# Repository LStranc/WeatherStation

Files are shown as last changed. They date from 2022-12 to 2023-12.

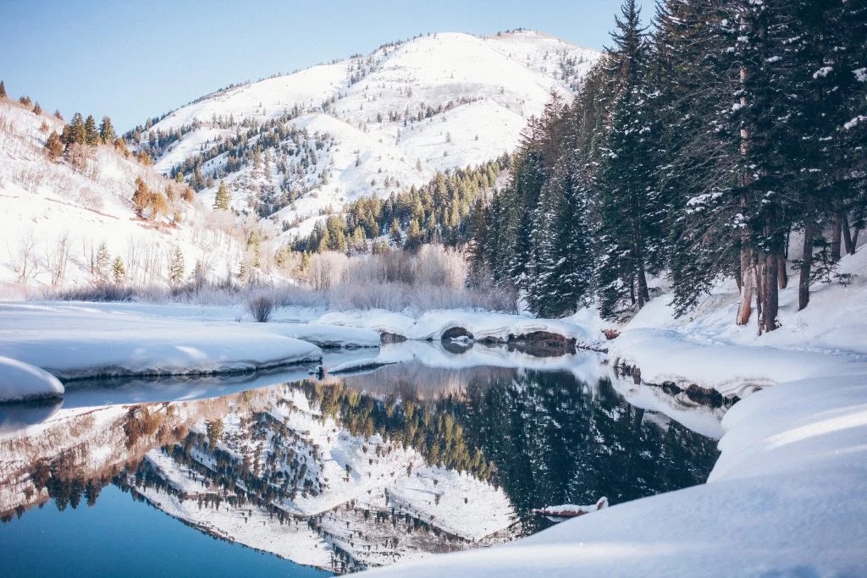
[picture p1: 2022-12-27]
Server_Code/weatherstation/pictures/UtahMountainLake.jpg

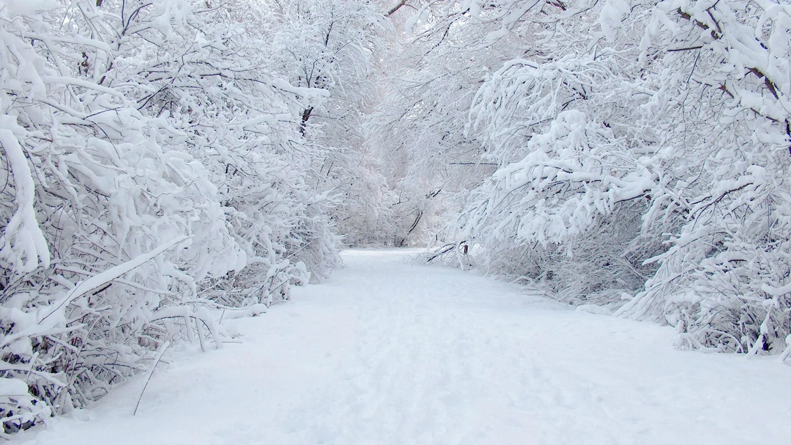
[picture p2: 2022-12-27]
Server_Code/weatherstation/pictures/pictures/snowfall.jpg

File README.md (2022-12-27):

# WeatherStation
The goal of this project was to build a cordless personal weather station that can be put in your own backyard. The weather station sends data to a server and you can analyze, store and use the data in anyway you want. 

This project includes c file to upload to the microcontroller, the server files used to store data in the sql database and display it to the website, and the schematic and pcb files for the actual hardware.

## Hardware
The Mircocontoller I used in this project is the esp32. A more generalized arudino code file is uploaded to this repo also. The weather station reads temperature, humidity, and pressure through a BME280 chip. It has a water sensor to sense if it is rainig. It uses the solar panel to tell how bright/sunny it is outside. This solar panel is also charging the lipo battery that it is powering the weather station. There is a uv sensor that tells us the uv index. There is Wind Sensor Rev P made by Modern Devices that is able to measure the windspeed. Also, there is a PWM5005 sensor which measures the air quality. The esp samples each sensor input then sends the data wirelessly to the server.

## Server
The server stores the data from the weather station and puts it in a mySQL database. The server also hosts a website where a client can interact with current and previously stored data. 

## Future 
This project is still in progress but the hope for the future is to implement an machine algorithm to try to forcast the upcoming weather.

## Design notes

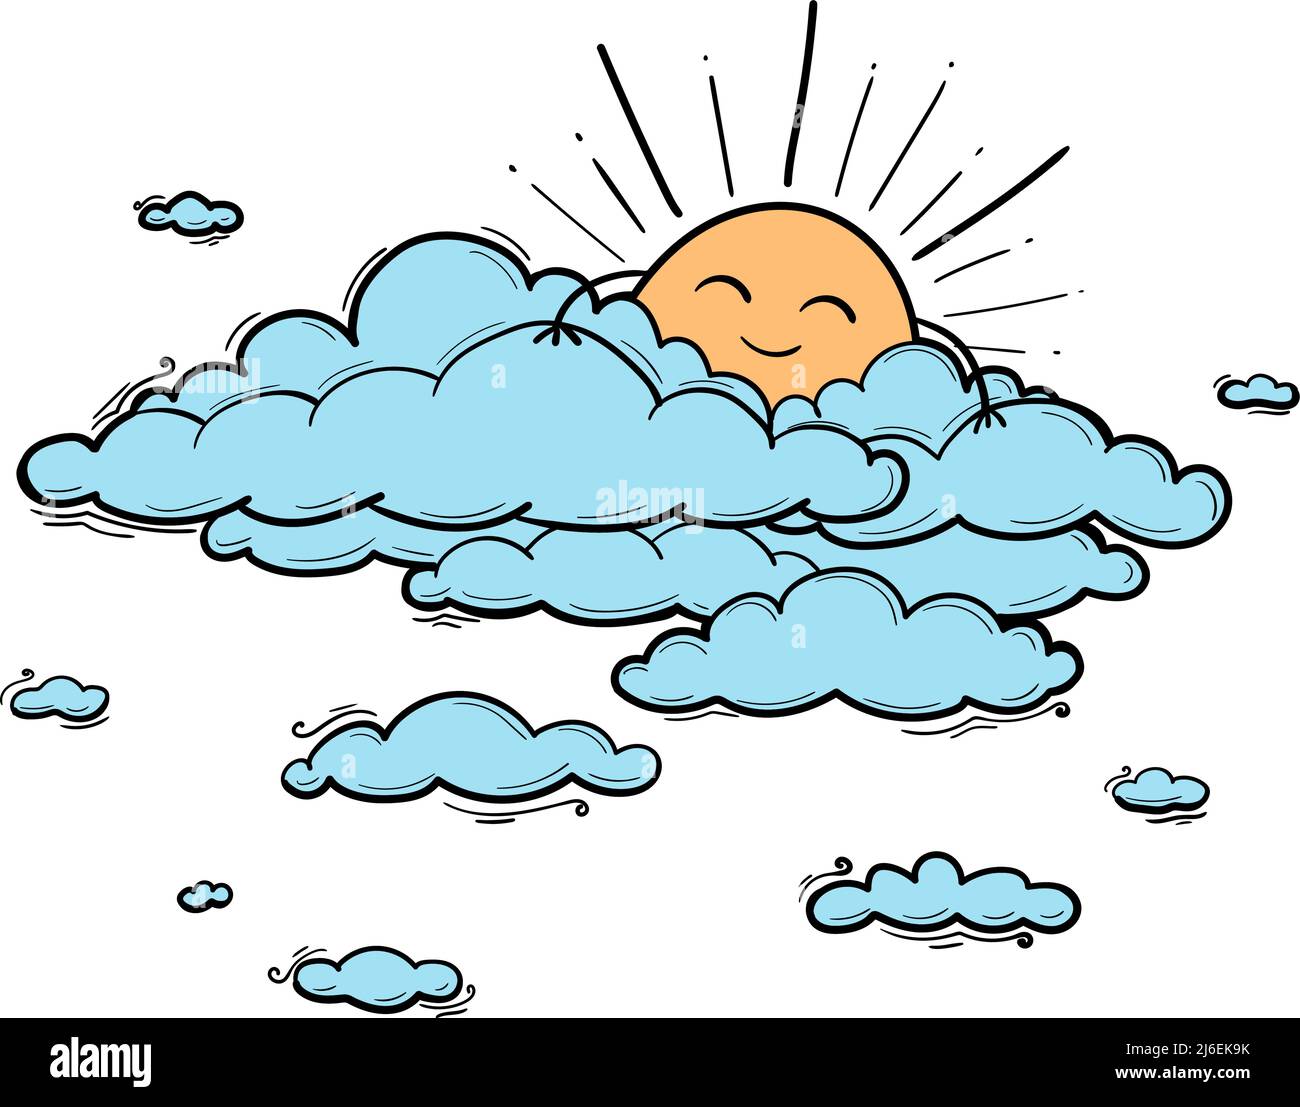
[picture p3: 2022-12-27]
Server_Code/weatherstation/pictures/CloudyDrawing.jpg

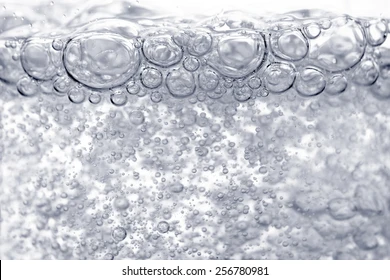
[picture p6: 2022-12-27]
Server_Code/weatherstation/pictures/boilingwater.webp

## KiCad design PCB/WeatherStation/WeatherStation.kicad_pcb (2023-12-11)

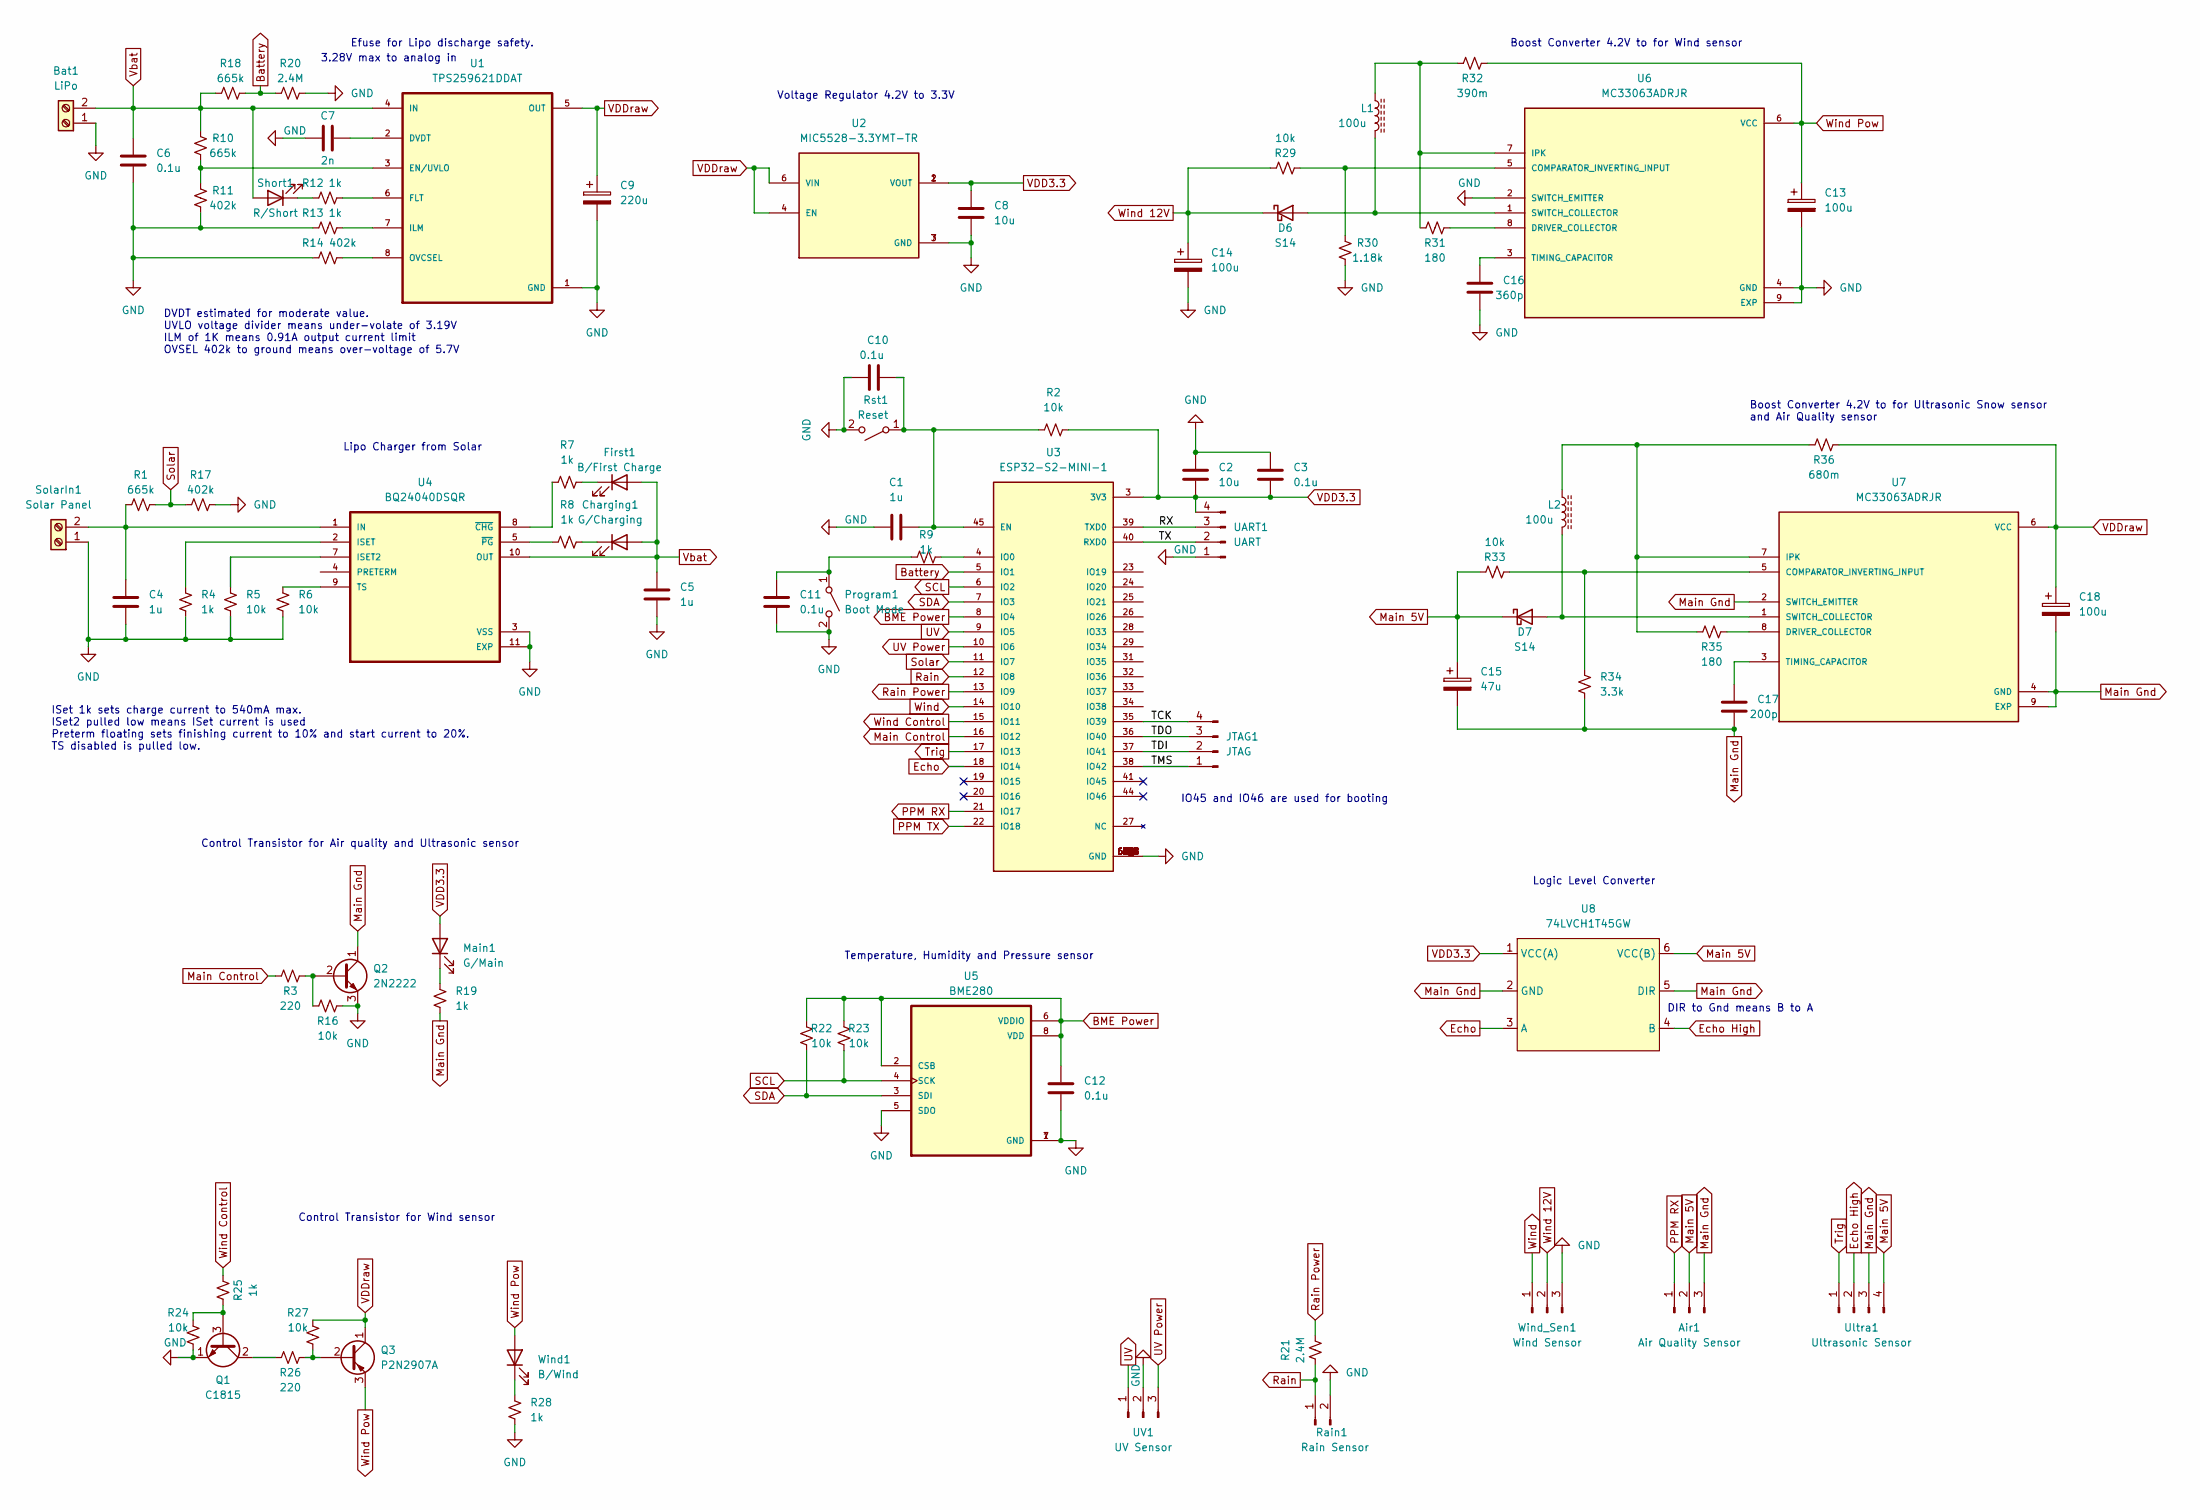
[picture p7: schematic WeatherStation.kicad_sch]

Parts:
Air1: Air Quality Sensor; PinHeader_1x03_P2.54mm_Vertical
Bat1: LiPo; TerminalBlock_Altech_AK300-2_P5.00mm
C1, C4, C5: 1u; C_0603_1608Metric_Pad1.08x0.95mm_HandSolder
C2, C8: 10u; C_0805_2012Metric_Pad1.18x1.45mm_HandSolder
C3, C6, C10, C11, C12: 0.1u; C_0603_1608Metric_Pad1.08x0.95mm_HandSolder
C7: 2n; C_0603_1608Metric_Pad1.08x0.95mm_HandSolder
C9: 220u; C_Radial_D5.0mm_H11.0mm_P2.00mm
C13, C18: 100u; C_Radial_D5.0mm_H11.0mm_P2.00mm
C14: 100u; C_Radial_D6.3mm_H11.0mm_P2.50mm
C15: 47u; C_Radial_D4.0mm_H7.0mm_P1.50mm
C16: 360p; C_0402_1005Metric_Pad0.74x0.62mm_HandSolder
C17: 200p; C_0603_1608Metric_Pad1.08x0.95mm_HandSolder
Charging1: G/Charging; LED_0603_1608Metric_Pad1.05x0.95mm_HandSolder
D6, D7: S14; D_SOD-123F
First1: B/First Charge; LED_0603_1608Metric_Pad1.05x0.95mm_HandSolder
JTAG1: JTAG; PinHeader_1x04_P2.54mm_Vertical
L1, L2: 100u; L_Toroid_Vertical_L10.2mm_W3.8mm_P3.8mm
Main1: G/Main; LED_0603_1608Metric_Pad1.05x0.95mm_HandSolder
Program1: Boot Mode; SW_PUSH_6mm_H5mm
Q1: C1815; TO-92
Q2: 2N2222; TO-92
Q3: P2N2907A; TO-92
R1, R10, R18: 665k; R_0603_1608Metric_Pad0.98x0.95mm_HandSolder
R2, R5, R6, R16, R22, R23, R24, R27, R29, R33: 10k; R_0603_1608Metric_Pad0.98x0.95mm_HandSolder
R3, R26: 220; R_0603_1608Metric_Pad0.98x0.95mm_HandSolder
R4, R7, R8, R9, R12, R13, R19, R25, R28: 1k; R_0603_1608Metric_Pad0.98x0.95mm_HandSolder
R11, R14, R17: 402k; R_0603_1608Metric_Pad0.98x0.95mm_HandSolder
R20, R21: 2.4M; R_0603_1608Metric_Pad0.98x0.95mm_HandSolder
R30: 1.18k; R_0603_1608Metric_Pad0.98x0.95mm_HandSolder
R31, R35: 180; R_0603_1608Metric_Pad0.98x0.95mm_HandSolder
R32: 390m; R_1206_3216Metric_Pad1.30x1.75mm_HandSolder
R34: 3.3k; R_0603_1608Metric_Pad0.98x0.95mm_HandSolder
R36: 680m; R_0603_1608Metric_Pad0.98x0.95mm_HandSolder
Rain1: Rain Sensor; PinHeader_1x02_P2.54mm_Vertical
Rst1: Reset; SW_PUSH_6mm_H5mm
Short1: R/Short; LED_0603_1608Metric_Pad1.05x0.95mm_HandSolder
SolarIn1: Solar Panel; TerminalBlock_Altech_AK300-2_P5.00mm
U1: TPS259621DDAT; VREG_LM5017MR_NOPB
U2: MIC5528-3.3YMT-TR; SON40P120X120X60-7N
U3: ESP32-S2-MINI-1; XCVR_ESP32-S2-MINI-1; PARTREV 1.0
U4: BQ24040DSQR; SON40P200X200X80-11N
U5: BME280; PSON65P250X250X100-8N
U6, U7: MC33063ADRJR; SON80P400X400X80-9N; PARTREV N
U8: 74LVCH1T45GW; SOT-363_SC-70-6_Handsoldering
UART1: UART; PinHeader_1x04_P2.54mm_Vertical
UV1: UV Sensor; PinHeader_1x03_P2.54mm_Vertical
Ultra1: Ultrasonic Sensor; PinHeader_1x04_P2.54mm_Vertical
Wind1: B/Wind; LED_0603_1608Metric_Pad1.05x0.95mm_HandSolder
Wind_Sen1: Wind Sensor; PinHeader_1x03_P2.54mm_Vertical

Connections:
/RX: U3.39 (TXD0), UART1.3
/TCK: JTAG1.4, U3.35 (IO39)
/TDI: JTAG1.2, U3.37 (IO41)
/TDO: JTAG1.3, U3.36 (IO40)
/TMS: JTAG1.1, U3.38 (IO42)
/TX: U3.40 (RXD0), UART1.2
BME Power: C12.1, R22.1, R23.1, U3.8 (IO4), U5.2 (CSB), U5.6 (VDDIO), U5.8 (VDD)
Battery: R18.2, R20.1, U3.5 (IO1)
Echo: U3.18 (IO14), U8.3 (A)
Echo High: U8.4 (B), Ultra1.2
GND: Bat1.1, C1.1, C2.1, C3.1, C4.1, C5.1, C6.2, C7.1, C8.2, C9.2, C10.2, C11.2, C12.2, C13.2, C14.2, C16.2, Program1.2 (B), Q1.1 (E), Q2.3 (E), R4.1, R5.1, R6.1, R11.2, R13.2, R14.2, R16.1, R17.2, R20.2, R24.2, R28.2, R30.1, Rain1.2, Rst1.2 (B), SolarIn1.1, U1.1 (GND), U2.3 (GND), U2.7 (GND), U3.1 (GND), U3.2 (GND), U3.30 (GND), U3.42 (GND), U3.43 (GND), U3.46 (GND), U3.47 (GND), U3.48 (GND), U3.49 (GND), U3.50 (GND), U3.51 (GND), U3.52 (GND), U3.53 (GND), U3.54 (GND), U3.55 (GND), U3.56 (GND), U3.57 (GND), U3.58 (GND), U3.59 (GND), U3.60 (GND), U3.61 (GND), U3.61_1 (GND), U3.61_2 (GND), U3.61_3 (GND), U3.61_4 (GND), U3.61_5 (GND), U3.61_6 (GND), U3.61_7 (GND), U3.61_8 (GND), U3.62 (GND), U3.63 (GND), U3.64 (GND), U3.65 (GND), U4.3 (VSS), U4.11 (EXP), U5.1 (GND), U5.5 (SDO), U5.7 (GND), U6.2 (SWITCH_EMITTER), U6.4 (GND), U6.9 (EXP), UART1.1, UV1.2, Wind_Sen1.3
Main 5V: Air1.2, C15.1, D7.1 (K), R33.2, U8.6 (VCC(B)), Ultra1.4
Main Control: R3.2, U3.16 (IO12)
Main Gnd: Air1.3, C15.2, C17.2, C18.2, Q2.1 (C), R19.2, R34.2, U7.2 (SWITCH_EMITTER), U7.4 (GND), U7.9 (EXP), U8.2 (GND), U8.5 (DIR), Ultra1.3
unnamed: C1.2, C10.1, R2.1, Rst1.1 (A), U3.45 (EN)
unnamed: C4.2, R1.1, SolarIn1.2, U4.1 (IN)
unnamed: C7.2, U1.2 (DVDT)
unnamed: C11.1, Program1.1 (A), R9.1
unnamed: C16.1, U6.3 (TIMING_CAPACITOR)
unnamed: C17.1, U7.3 (TIMING_CAPACITOR)
unnamed: Charging1.1 (K), R8.1
unnamed: D6.2 (A), L1.2, U6.1 (SWITCH_COLLECTOR)
unnamed: D7.2 (A), L2.2, U7.1 (SWITCH_COLLECTOR)
unnamed: First1.1 (K), R7.1
unnamed: L1.1, R31.1, R32.1, U6.7 (IPK)
unnamed: L2.1, R35.1, R36.1, U7.7 (IPK)
unnamed: Main1.1 (K), R19.1
unnamed: Q1.2 (C), R26.1
unnamed: Q1.3 (B), R24.1, R25.2
unnamed: Q2.2 (B), R3.1, R16.2
unnamed: Q3.2 (B), R26.2, R27.2
unnamed: R4.2, U4.2 (ISET)
unnamed: R5.2, U4.7 (ISET2)
unnamed: R6.2, U4.9 (TS)
unnamed: R7.2, U4.8 (~CHG)
unnamed: R8.2, U4.5 (~PG)
unnamed: R9.2, U3.4 (IO0)
unnamed: R10.2, R11.1, U1.3 (EN/UVLO)
unnamed: R12.1, U1.6 (FLT)
unnamed: R12.2, Short1.1 (K)
unnamed: R13.1, U1.7 (ILM)
unnamed: R14.1, U1.8 (OVCSEL)
unnamed: R28.1, Wind1.1 (K)
unnamed: R29.1, R30.2, U6.5 (COMPARATOR_INVERTING_INPUT)
unnamed: R31.2, U6.8 (DRIVER_COLLECTOR)
unnamed: R33.1, R34.1, U7.5 (COMPARATOR_INVERTING_INPUT)
unnamed: R35.2, U7.8 (DRIVER_COLLECTOR)
PPM RX: Air1.1, U3.21 (IO17)
PPM TX: U3.22 (IO18)
Rain: R21.1, Rain1.1, U3.12 (IO8)
Rain Power: R21.2, U3.13 (IO9)
SCL: R23.2, U3.6 (IO2), U5.4 (SCK)
SDA: R22.2, U3.7 (IO3), U5.3 (SDI)
Solar: R1.2, R17.1, U3.11 (IO7)
Trig: U3.17 (IO13), Ultra1.1
UV: U3.9 (IO5), UV1.1
UV Power: U3.10 (IO6), UV1.3
VDD3.3: C2.2, C3.2, C8.1, Main1.2 (A), R2.2, U2.1 (VOUT), U2.2 (VOUT), U3.3 (3V3), U8.1 (VCC(A)), UART1.4
VDDraw: C9.1, C18.1, Q3.1 (C), R27.1, R36.2, U1.5 (OUT), U2.4 (EN), U2.6 (VIN), U7.6 (VCC)
Vbat: Bat1.2, C5.2, C6.1, Charging1.2 (A), First1.2 (A), R10.1, R18.1, Short1.2 (A), U1.4 (IN), U4.10 (OUT)
Wind: U3.14 (IO10), Wind_Sen1.1
Wind 12V: C14.1, D6.1 (K), R29.2, Wind_Sen1.2
Wind Control: R25.1, U3.15 (IO11)
Wind Pow: C13.1, Q3.3 (E), R32.2, U6.6 (VCC), Wind1.2 (A)

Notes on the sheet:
Temperature, Humidity and Pressure sensor
3.28V max to analog in
DVDT estimated for moderate value. UVLO voltage divider means under-volate of 3.19V ILM of 1K means 0.91A output current limit OVSEL 402k to ground means over-voltage of 5.7V
IO45 and IO46 are used for booting
Logic Level Converter
DIR to Gnd means B to A
Lipo Charger from Solar
Boost Converter 4.2V to for Wind sensor
ISet 1k sets charge current to 540mA max. ISet2 pulled low means ISet current is used Preterm floating sets finishing current to 10% and start current to 20%. TS disabled is pulled low.
Control Transistor for Air quality and Ultrasonic sensor
Voltage Regulator 4.2V to 3.3V
Efuse for Lipo discharge safety.
Control Transistor for Wind sensor
Boost Converter 4.2V to for Ultrasonic Snow sensor and Air Quality sensor

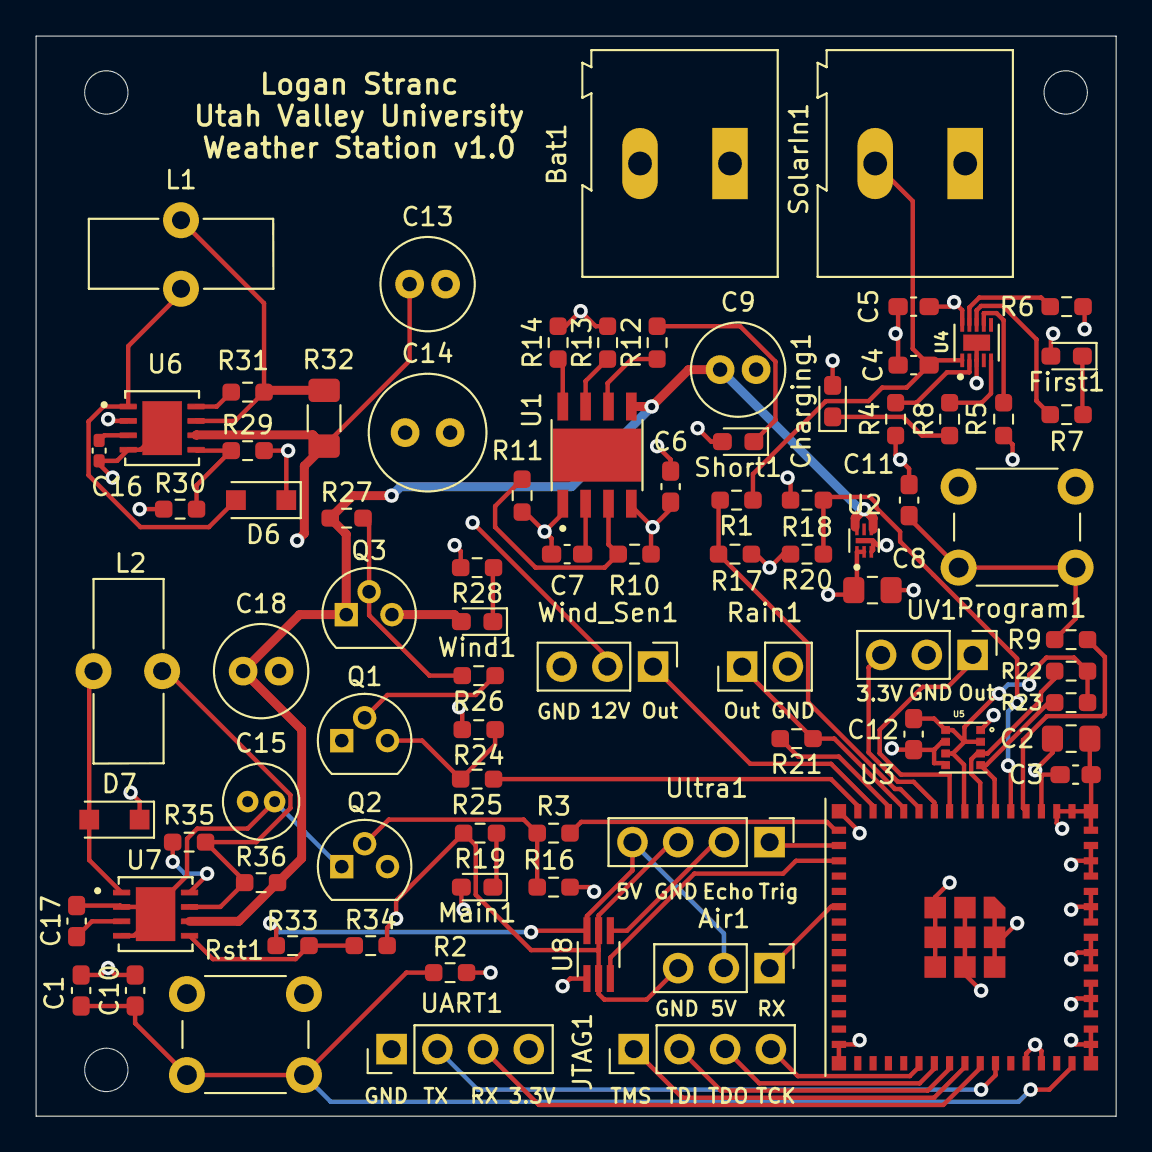
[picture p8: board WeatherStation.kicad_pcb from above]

Board: 4 copper layers, 60.0 x 60.0 mm, 84 parts (0 on the bottom side), 63 nets.

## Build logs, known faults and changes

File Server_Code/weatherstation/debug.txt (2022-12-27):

New record Failed,
INSERT INTO weatherData (Temp, Humidity, Pressure, Precipitation, WindSpeed, Part0_3, Part0_5, Part1, Part2_5, Part5, Part10, UVIndex, SnowFall, Battery) VALUES (,,, 'Snowing',,,,,,,,0,86,)
You have an error in your SQL syntax; check the manual that corresponds to your MySQL server version for the right syntax to use near ',,, 'Snowing',,,,,,,,0,86,)' at line 1

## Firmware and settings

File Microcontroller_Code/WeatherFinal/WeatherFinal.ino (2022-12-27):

#include "LowPower.h" //for sleep periods of microcontroller
#include <SoftwareSerial.h> // for serial communication needed for esp and air sensor
#include "Adafruit_PM25AQI.h" //air sensor library for easy interface
//BMP280 Packages
#include <Wire.h>
#include <Adafruit_Sensor.h>
#include <Adafruit_BME280.h>

#include "encrypt.h" //import ip and wifi connection information

// pins tx(pin 0) and rx(pin 1) are left floating
#define TRIGPIN 4 //ultrasonic trigger
#define ECHOPIN 5 //ultrasonic echo
#define POWERESP 8 //power for esp
#define POWERMAIN 9 //power for bme, rain, and uv sensors
#define POWERWIND 10 //power for wind sensor
#define BATTERYPIN A1 //battery voltage pin
#define SUNPIN A2 // solar panel voltage pin
#define WINDPIN A3 //wind sensor pin
#define UVPIN A6  // uv light sensor pin
#define RAINPIN A7 //Rain sensor pin

#define SERIALSPEED 115200               
#define DEBUG false 
SoftwareSerial esp8266(11,12);                   

SoftwareSerial pmSerial(2, 3); //only tx pin 2 is used, rx pin 3 is floating
Adafruit_PM25AQI aqi = Adafruit_PM25AQI();
PM25_AQI_Data data;

Adafruit_BME280 bme; // creates I2C BMP280 object, uses pins

float temperature = 0.0;
long pressure = 0;
float humidity = 0;
int precipitation = 0;
int sun = 800;
float windSpeed = 0;
int uvIndex = 1;
long cm = 0;
int battery = 0;

 
void setup(){
  Serial.begin(SERIALSPEED); 
  intPins();
}

void loop(){
  //sun = analogRead(SUNPIN); //store sun voltage reading
  deepSleep(30);
  battery = analogRead(BATTERYPIN); //store battery voltage reading
  delay(5000);
  readMainBus(); //reads data from bme, rain, and uv sensor
  delay(5000); // heavy load to heavy load, let circuit reach steady state 
  readWindBus(); // reads data from wind sensor
  delay(5000);
  sendWiFiOnBus(); //powerup and initialize esp and send weather data
  deepSleep(5); // sleep for 5*8= 40seconds
}

void deepSleep(int EightSecondIntervals){
  int i = 0;
  while(i<EightSecondIntervals){
  LowPower.powerDown(SLEEP_8S, ADC_OFF, BOD_OFF); //deep sleep for 8 seconds
  i++;
  } 
}

void intPins(){
  pinMode(POWERMAIN,OUTPUT);
  pinMode(POWERWIND,OUTPUT);
  pinMode(POWERESP,OUTPUT);
  digitalWrite(POWERMAIN, LOW);
  digitalWrite(POWERWIND, LOW);
  digitalWrite(POWERESP, LOW);

  
  //Ultrasonic sensor setup pins
  pinMode(TRIGPIN, INPUT); //InputPullup = 28uA, Input = 0 uA
  pinMode(ECHOPIN, INPUT); //InputPullup = 33 uA, Input
}

void readMainBus(){
  digitalWrite(POWERMAIN,HIGH); //give main bus power
  pinMode(TRIGPIN,OUTPUT);
  pinMode(ECHOPIN, INPUT); // set echo pin back to input
  delay(500);
  bme.begin(0x76); // bme initialize
  delay(2000); 
  temperature = bme.readTemperature(); //store temperature
  pressure = bme.readPressure(); //store pressure
  humidity = bme.readHumidity(); //store humidity
  delay(500);
  uvIndex = analogRead(UVPIN); //store uv voltage reading
  precipitation = analogRead(RAINPIN); //store precipitation voltage reading
  delay(1000);
  snowSensorRead(); // read snow height data
  delay(15000); //let sensor warmup for 15 seconds  
  airSensorRead(); // read air quality data 
  pinMode(TRIGPIN, INPUT); //set trigpin back to input pullup to convserve power
  digitalWrite(POWERMAIN,LOW);
}

void airSensorRead(){
  pmSerial.begin(9600); //begin serial communication with air sensor
  while (! aqi.begin_UART(&pmSerial)){ // wait while air sensor has not begun serial communication
    digitalWrite(13, HIGH);
    delay(1000);
    digitalWrite(13,LOW);
    delay(1000);
  }
  while (! aqi.read(&data) && data.particles_03um <= 1) { //wait until good data is read, values are stored in data struct
    digitalWrite(13, HIGH);
    delay(250);
    digitalWrite(13,LOW);
    delay(250);
  }  
}

void snowSensorRead(){
  long duration;
  //Ultrasonic Snow Sensor Reading
  // The sensor is triggered by a HIGH pulse of 10 or more microseconds.
  // Give a short LOW pulse beforehand to ensure a clean HIGH pulse:.
  digitalWrite(TRIGPIN, LOW);
  delayMicroseconds(5);
  digitalWrite(TRIGPIN, HIGH);
  delayMicroseconds(10);
  digitalWrite(TRIGPIN, LOW);
  // Read the signal from the sensor: a HIGH pulse whose
  // duration is the time (in microseconds) from the sending
  // of the ping to the reception of its echo off of an object.
  duration = pulseIn(ECHOPIN, HIGH);
  // Convert the time into a distance
  cm = (duration/2) / 29.1;     // Divide by 29.1 or multiply by 0.0343
  //Assuming the sensor is 86 cm from the ground the difference between the distance
  // the ultrasonic sensor found and the actual ground will be the amount of snowfall
  // this calculation is done server side
}

void readWindBus(){
  digitalWrite(POWERWIND,HIGH); // give power to 3.3 to 12V step for wind sensor
  delay(30000); // wait a while for the sensor to heat up
  windSpeed = analogRead(WINDPIN);
  windSpeed =  pow(((((float)windSpeed) - 264.0) / 85.6814), 3.36814); //equation converts voltage read at output into wind speed in mph
  digitalWrite(POWERWIND,LOW); // turn off wind bus
}

String sendData(String command, const int timeout, boolean debug)
{
    String response = "";                                             
    esp8266.print(command);                                          
    long int time = millis();                                      
    while( (time+timeout) > millis())                                 
    {      
      while(esp8266.available())                                      
      {
        char c = esp8266.read();                                     
        response+=c;                                                  
      }  
    }    
    if(debug)                                                        
    {
      //Serial.print(response);
    }    
    return response;                                                  
}

void initWifiModule()
{
  String wifi_username = get_WiFi_Username();
  String wifi_password = get_WiFi_Password();
  
  esp8266.begin(SERIALSPEED);
  delay(1000);
  sendData("AT+RST\r\n", 2000, DEBUG); 
  sendData("AT+CWJAP=\"" + wifi_username + "\",\"" + wifi_password + "\"\r\n", 2000, DEBUG);        
  delay (3000);
  sendData("AT+CWMODE=1\r\n", 2000, DEBUG);                                          
  delay (1500);
  sendData("AT+CIFSR\r\n", 2000, DEBUG);                                                                    
  delay (1500);
  sendData("AT+CIPMUX=1\r\n", 2000, DEBUG);                                                                            
}

void sendWeatherData(){
  String ip = get_IP();
  
  sendData("AT+CIPSTART=0,\"TCP\",\"" + ip + "\",80\r\n", 6000, DEBUG); //attempt to start tcp communication with server port 80                              
  delay(500);
  String message = String("GET ") + "/receiverDB.php?" + 
              "temp="+ temperature +
              "&humidity=" + humidity +
              "&pressure=" + pressure +
              "&precipitation=" + precipitation +
              "&windspeed=" + windSpeed +
              "&sun=" + sun +
              "&parta=" + data.particles_03um +
              "&partb=" + data.particles_05um +
              "&partc=" + data.particles_10um +
              "&partd=" + data.particles_25um +
              "&parte=" + data.particles_50um +
              "&partf=" + data.particles_100um +
              "&uvindex=" + uvIndex +
              "&snowfall=" + cm +
              "&battery=" + battery + 
              " HTTP/1.1\r\n" + 
              "Host: " + ip + "\r\n\r\n"; //GET request of all data to be sent to server_ip/receiverDB.php     
   String cipSend = "AT+CIPSEND=0,";
   cipSend +=message.length(); 
   cipSend +="\r\n";
   delay(2000);
   sendData(cipSend,4000,DEBUG); //send full GET request message
   delay(2000);
   sendData(message,4000,DEBUG); //resend message
   String closeCommand = "AT+CIPCLOSE=0"; 
   closeCommand+="\r\n";  
   delay(2000);  
   sendData(closeCommand,4000,DEBUG); //close connection with server
}

void sendWiFiOnBus(){
  digitalWrite(POWERESP, HIGH);
  delay(500);
  initWifiModule(); //initialize esp on network settings
  delay(2000);
  sendWeatherData();
  delay(1000);
  digitalWrite(POWERESP,LOW);
}

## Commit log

2023-04-28 Rough draft of Control PCB with Gerbers
    [WeatherStation-B_Cu.gbl, WeatherStation-B_Mask.gbs, WeatherStation-B_Paste.gbp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]
2023-12-11 PCB Gerber Files
    [WeatherStation-B_Cu.gbl, WeatherStation-B_Mask.gbs, WeatherStation-B_Paste.gbp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]
